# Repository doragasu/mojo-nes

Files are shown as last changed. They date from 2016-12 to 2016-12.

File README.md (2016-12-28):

# mojo-nes

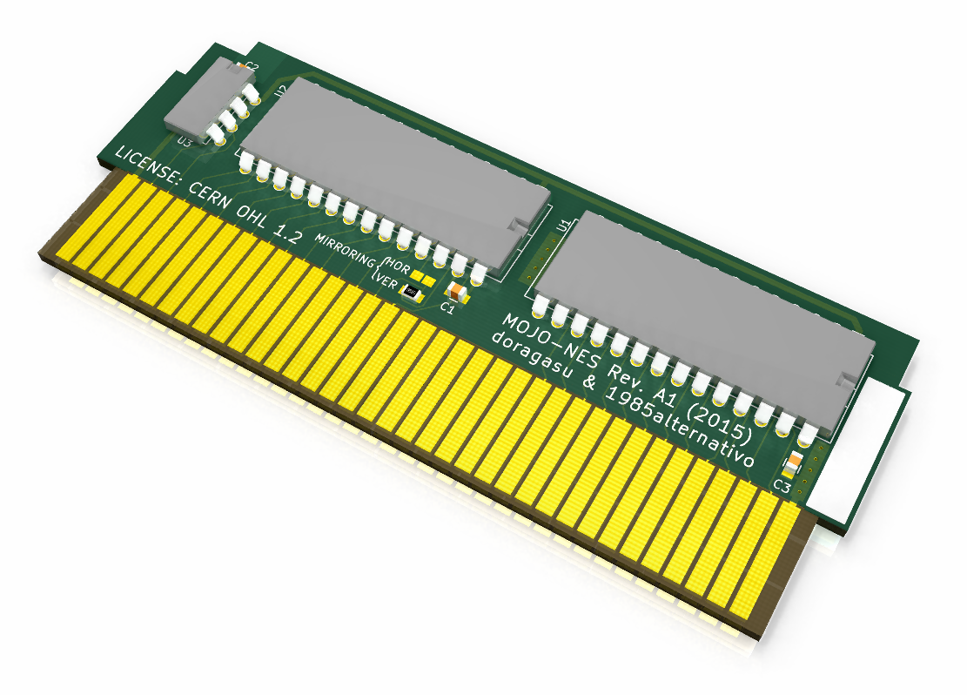
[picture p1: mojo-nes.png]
mojo-nes


NES cartridge with no mapper support. Initially created to host homebrew projects from the infamous [THE MOJON-TWINS](http://www.mojontwins.com/), and some more from [1985alternativo](http://www.fasebonus.net/1985alternativo/).

## License
mojo-nes is licensed under the [CERN OHL 1.2](http://www.ohwr.org/licenses/cern-ohl/v1.2) license. You are free to study, distribute and make modifications to the Documentation, under the aforementioned license terms. You are also free to make cartridges derived from the Documentation for non-commercial purposes. If you want to make a commercial Product using this Documentation, please contact me to obtain a licence.

## About CAD files
CAD design files are for KiCAD Open Source electronics design suite. Please install latest version along with KiCAD libraries to open it. When opening schematic, KiCAD will most likely complain about missing library "doragasu". Despite this warning, the schematic should load nicely (using the cached libraries). To avoid this message, install [the missing library](https://github.com/doragasu/doragasu-kicad-lib) and make sure to configure it in the schematic editor.

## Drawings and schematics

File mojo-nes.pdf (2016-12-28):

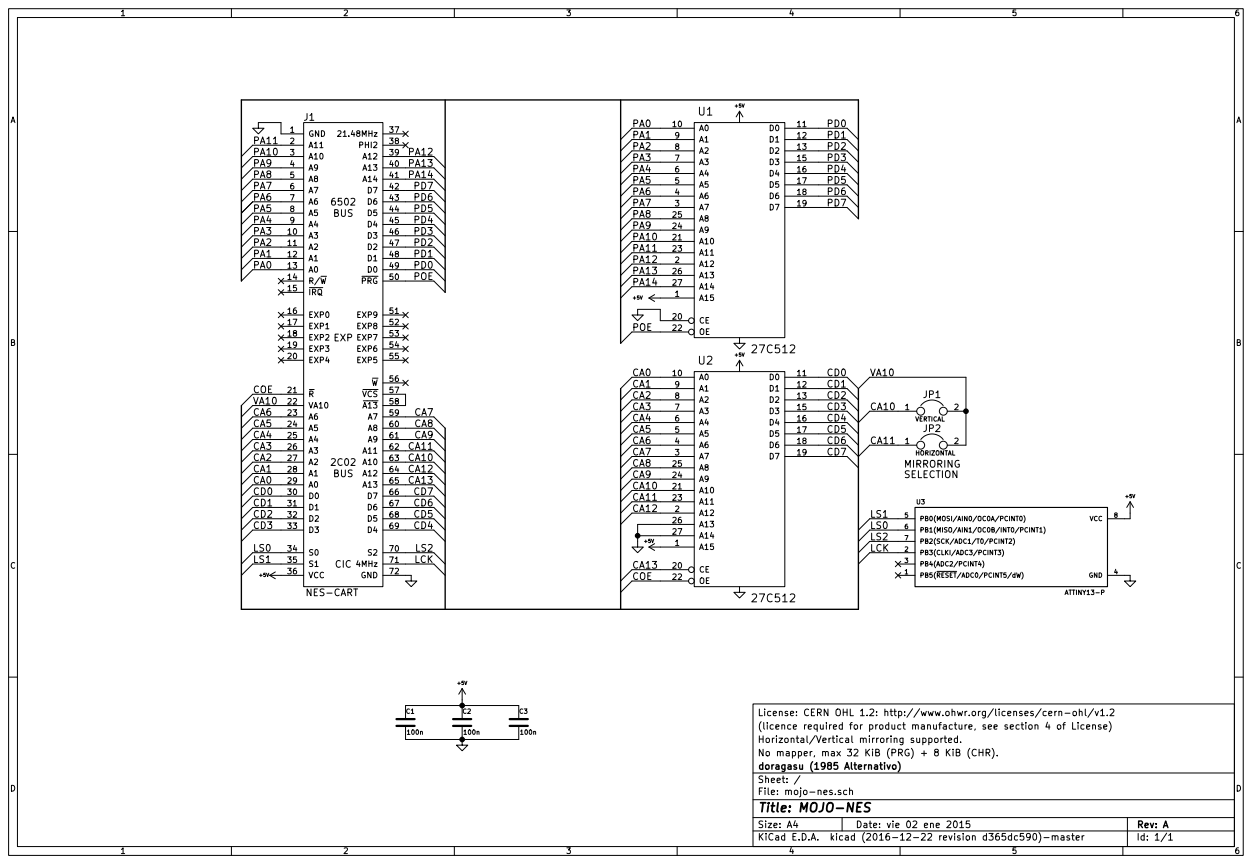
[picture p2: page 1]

LCK

LS1 | LCK

License: CERN OHL 1.2: http://www.ohwr.org/licenses/cern-ohl/v1.2
(licence required for product manufacture, see section 4 of License)
Horizontal/Vertical mirroring supported.
No mapper, max 32 KiB (PRG) + 8 KiB (CHR).
File: mojo-nes.sch Sheet: / doragasu (1985 Alternativo)

Id: 1/1 Title: MOJO-NES

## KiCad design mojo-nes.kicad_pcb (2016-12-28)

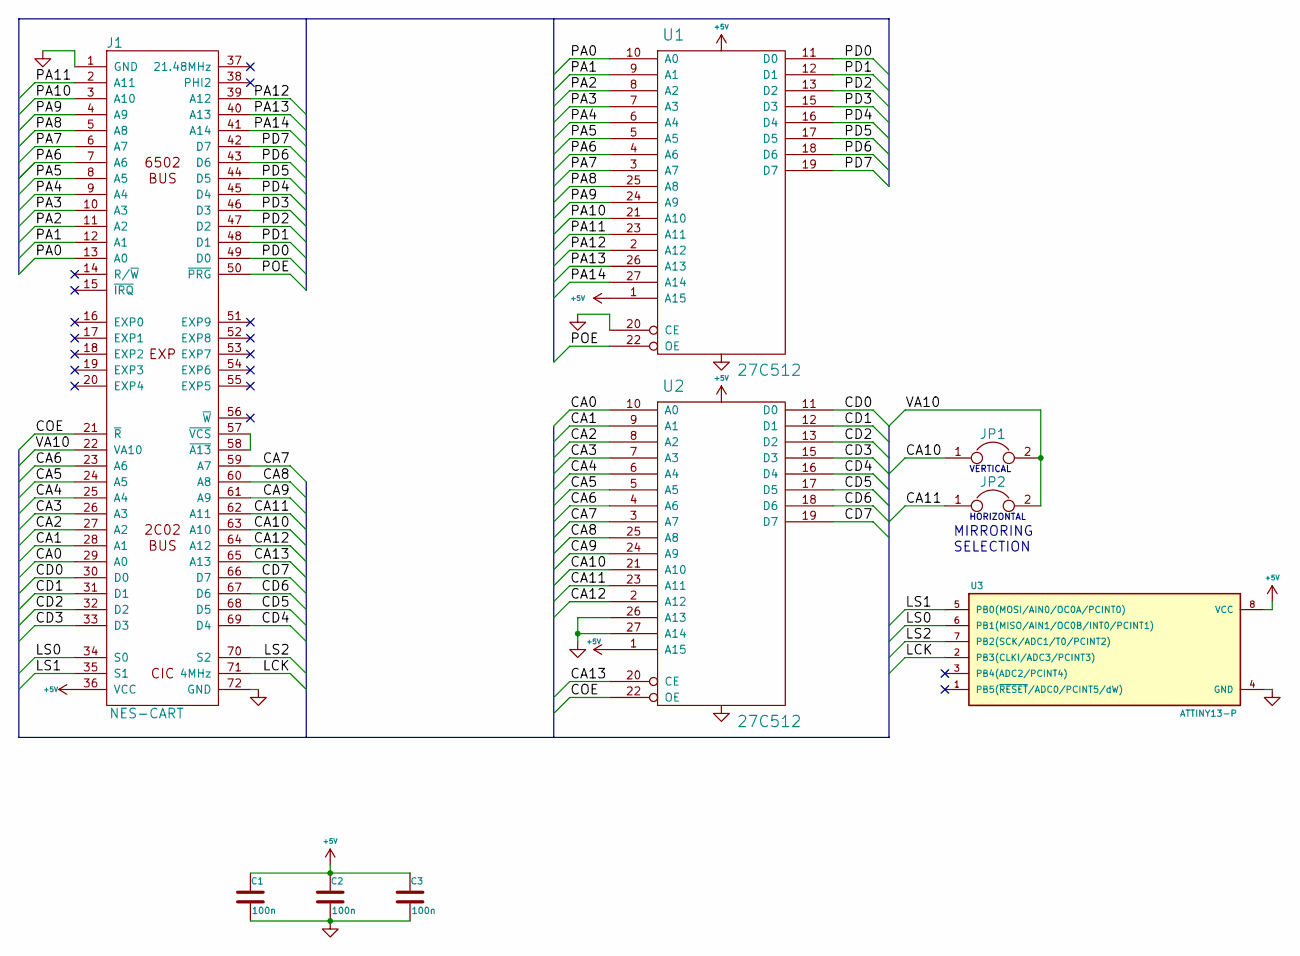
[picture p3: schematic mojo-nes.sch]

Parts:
C1, C2, C3: 100n; C_0805
J1: NES-CART; NES_CART_FINGERS
JP1, JP2: JUMPER; JUMPER_0805
U1, U2: 27C512; DIP-28__600
U3: ATTINY13-P; DIP-8__300

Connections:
+5V: C1.1, C2.1, C3.1, J1.36 (VCC), U1.1 (A15), U1.28 (VCC), U2.1 (A15), U2.28 (VCC), U3.8 (VCC)
/CA0: J1.29 (A0), U2.10 (A0)
/CA1: J1.28 (A1), U2.9 (A1)
/CA2: J1.27 (A2), U2.8 (A2)
/CA3: J1.26 (A3), U2.7 (A3)
/CA4: J1.25 (A4), U2.6 (A4)
/CA5: J1.24 (A5), U2.5 (A5)
/CA6: J1.23 (A6), U2.4 (A6)
/CA7: J1.59 (A7), U2.3 (A7)
/CA8: J1.60 (A8), U2.25 (A8)
/CA9: J1.61 (A9), U2.24 (A9)
/CA10: J1.63 (A10), JP1.1, U2.21 (A10)
/CA11: J1.62 (A11), JP2.1, U2.23 (A11)
/CA12: J1.64 (A12), U2.2 (A12)
/CA13: J1.65 (A13), U2.20 (CE)
/CD0: J1.30 (D0), U2.11 (D0)
/CD1: J1.31 (D1), U2.12 (D1)
/CD2: J1.32 (D2), U2.13 (D2)
/CD3: J1.33 (D3), U2.15 (D3)
/CD4: J1.69 (D4), U2.16 (D4)
/CD5: J1.68 (D5), U2.17 (D5)
/CD6: J1.67 (D6), U2.18 (D6)
/CD7: J1.66 (D7), U2.19 (D7)
/COE: J1.21 (~R), U2.22 (OE)
/LCK: J1.71 (4MHz), U3.2 (PB3(CLKI/ADC3/PCINT3))
/LS0: J1.34 (S0), U3.6 (PB1(MISO/AIN1/OC0B/INT0/PCINT1))
/LS1: J1.35 (S1), U3.5 (PB0(MOSI/AIN0/OC0A/PCINT0))
/LS2: J1.70 (S2), U3.7 (PB2(SCK/ADC1/T0/PCINT2))
/PA0: J1.13 (A0), U1.10 (A0)
/PA1: J1.12 (A1), U1.9 (A1)
/PA2: J1.11 (A2), U1.8 (A2)
/PA3: J1.10 (A3), U1.7 (A3)
/PA4: J1.9 (A4), U1.6 (A4)
/PA5: J1.8 (A5), U1.5 (A5)
/PA6: J1.7 (A6), U1.4 (A6)
/PA7: J1.6 (A7), U1.3 (A7)
/PA8: J1.5 (A8), U1.25 (A8)
/PA9: J1.4 (A9), U1.24 (A9)
/PA10: J1.3 (A10), U1.21 (A10)
/PA11: J1.2 (A11), U1.23 (A11)
/PA12: J1.39 (A12), U1.2 (A12)
/PA13: J1.40 (A13), U1.26 (A13)
/PA14: J1.41 (A14), U1.27 (A14)
/PD0: J1.49 (D0), U1.11 (D0)
/PD1: J1.48 (D1), U1.12 (D1)
/PD2: J1.47 (D2), U1.13 (D2)
/PD3: J1.46 (D3), U1.15 (D3)
/PD4: J1.45 (D4), U1.16 (D4)
/PD5: J1.44 (D5), U1.17 (D5)
/PD6: J1.43 (D6), U1.18 (D6)
/PD7: J1.42 (D7), U1.19 (D7)
/POE: J1.50 (~PRG), U1.22 (OE)
/VA10: J1.22 (VA10), JP1.2, JP2.2
GND: C1.2, C2.2, C3.2, J1.1 (GND), J1.72 (GND), U1.14 (GND), U1.20 (CE), U2.14 (GND), U2.26 (A13), U2.27 (A14), U3.4 (GND)
unnamed: J1.57 (~VCS), J1.58 (~A13)

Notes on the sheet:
VERTICAL
HORIZONTAL
MIRRORING SELECTION

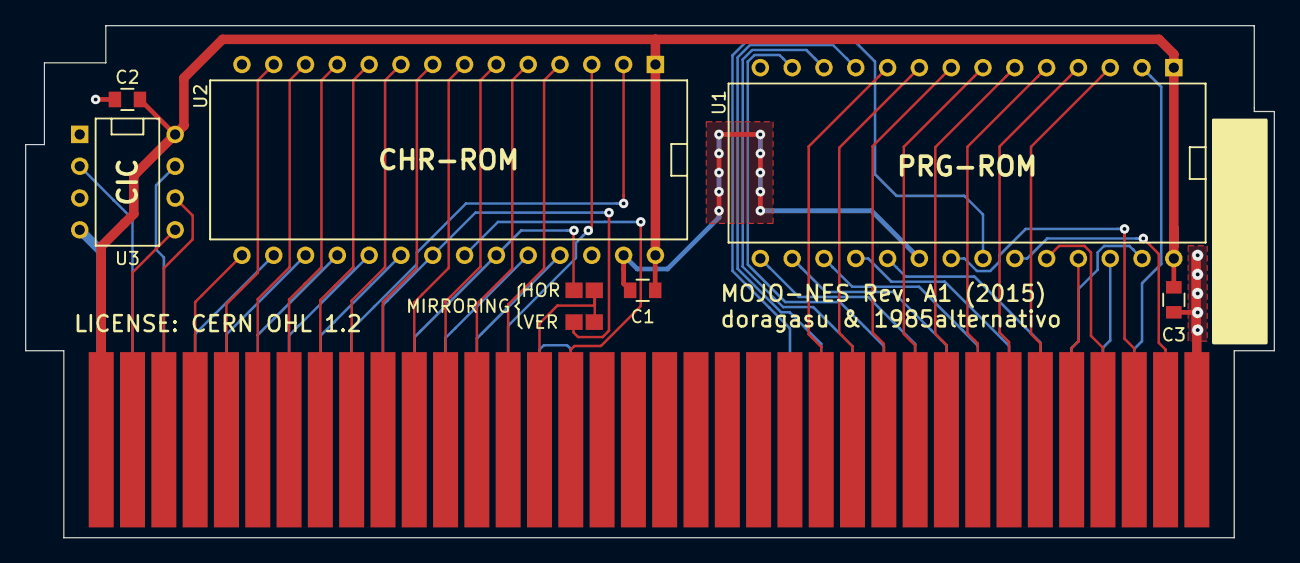
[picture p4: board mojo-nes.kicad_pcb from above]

Board: 2 copper layers, 99.7 x 40.9 mm, 9 parts (0 on the bottom side), 55 nets.

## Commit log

2016-12-28 Added design files.
    [mojo-nes-B.Cu.gbr, mojo-nes-B.Mask.gbr, mojo-nes-Edge.Cuts.gbr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]
2016-12-28 Added 3D footprints and PCB render.
    [mojo-nes.kicad_pcb]
2016-12-28 Updated PCB render.
